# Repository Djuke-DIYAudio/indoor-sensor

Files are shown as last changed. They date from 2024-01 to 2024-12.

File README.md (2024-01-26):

# Indoor sensor
This project contains the open source design files of an affordable indoor air sensor that can accurately measure CO2 level, Temperature, Humidity and Pressure. It contains a ESP8266 wi-fi module making it easy to integrate with your home automation system. 

Possible use cases:
* Monitoring sensor values over time
* Switching of air ventilation based on CO2 or humidity level
* Regulating room temperature (airco or heater)

# Design

## Considerations
At the moment the design considerations are:

* MH-Z19 sensor for measuring CO2 ppm
* BME280 sensor for measuring temperature, humidity and pressure sensor
* ESP8266 module to easily integrate with WIFI in the smart home
* red/green dual LED for level indication
  - Green, PPM < 800
  - Yellow/Orange, 800 < PPM < 1400
  - Red, PPM > 1400
* Connectors for optional 0.91 inch or 0.96 inch SSD1306 display
* Sales price around 25 euros

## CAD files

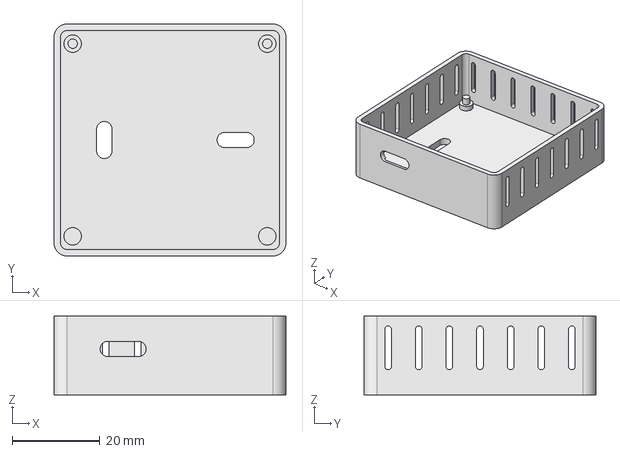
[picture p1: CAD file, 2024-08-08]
Design/Housing/Housing-Bottom.FCStd
53.0 x 53.0 x 18.0 mm

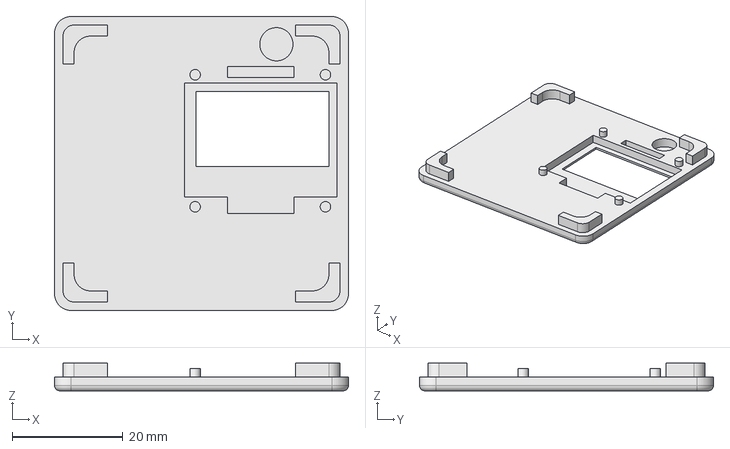
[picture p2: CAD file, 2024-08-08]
Design/Housing/Housing-Top.FCStd
53.0 x 53.0 x 5.00 mm

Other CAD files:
Design/Housing/Housing-Bottom.stl
Design/Housing/Housing-Top.stl

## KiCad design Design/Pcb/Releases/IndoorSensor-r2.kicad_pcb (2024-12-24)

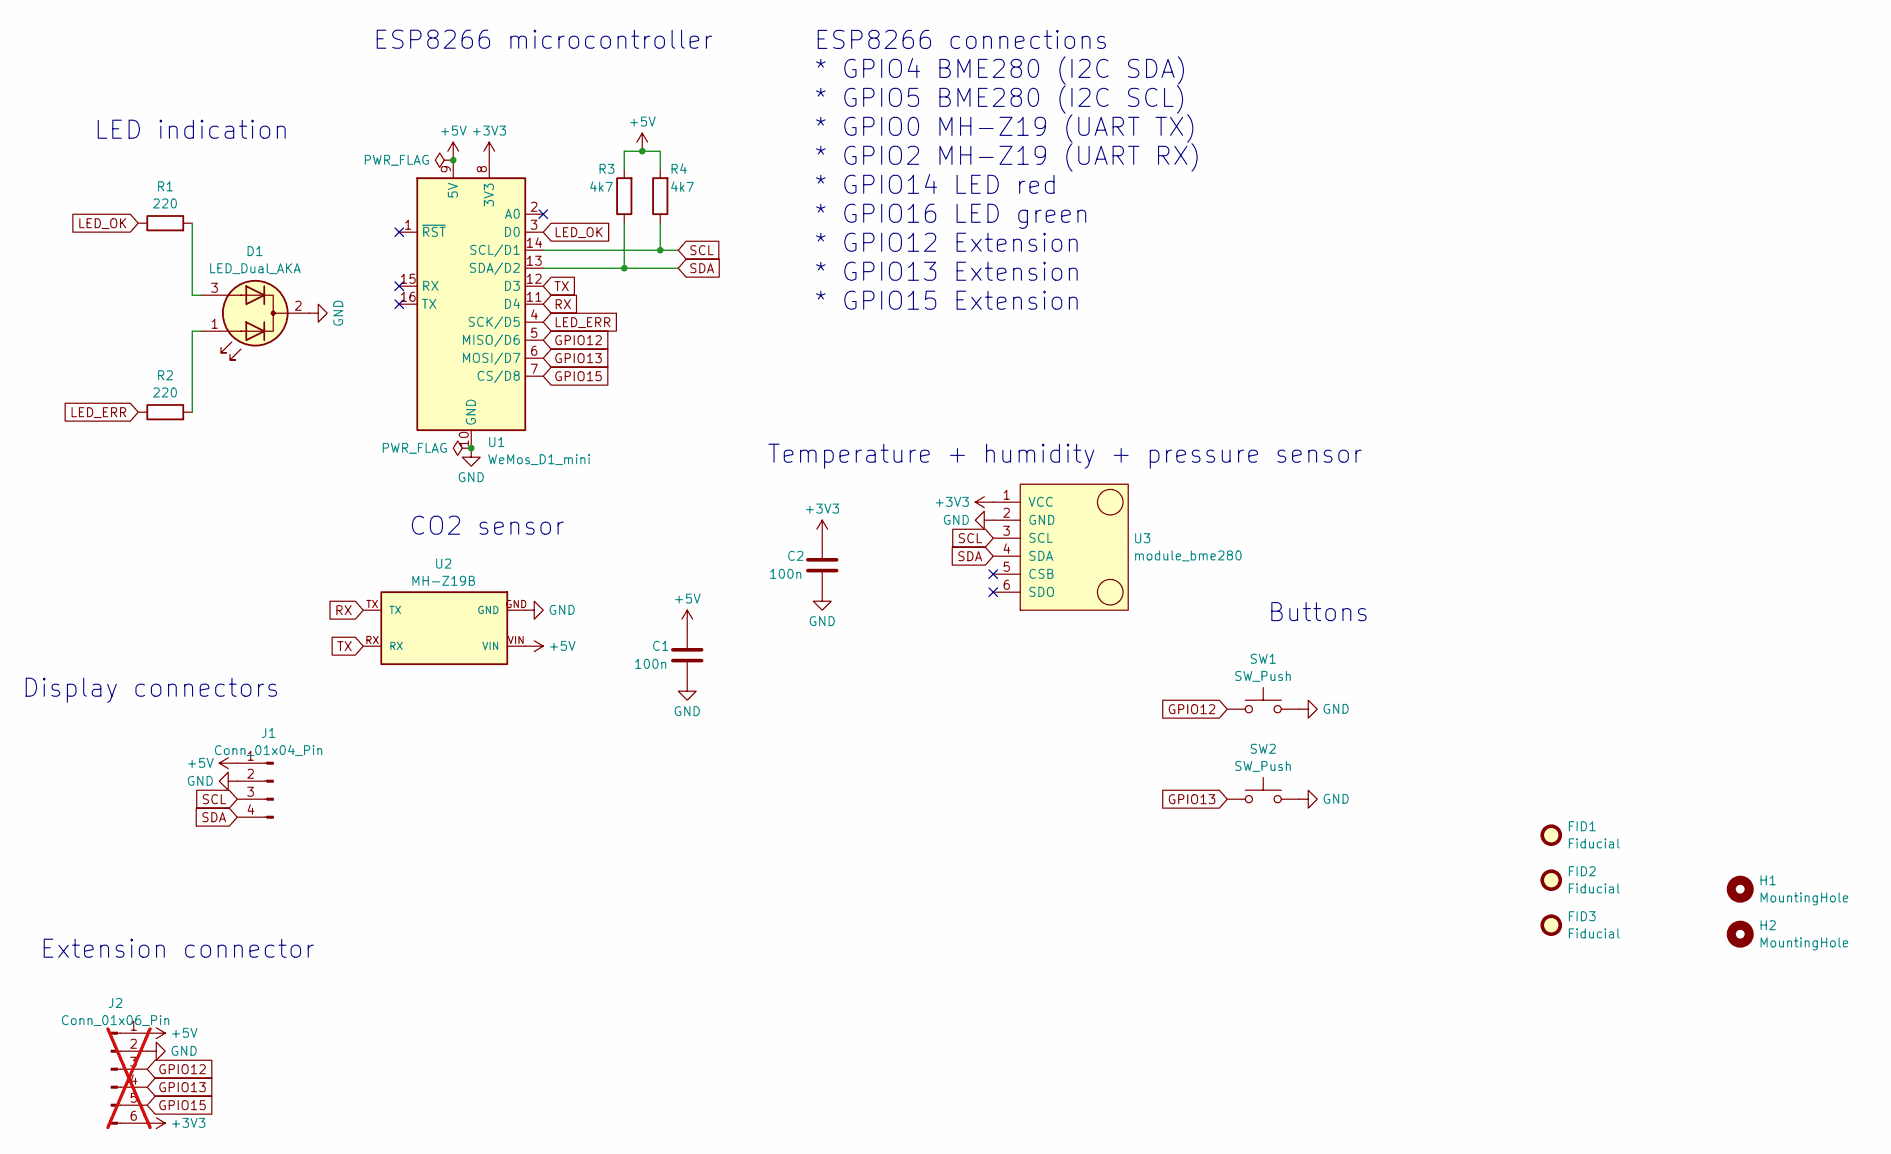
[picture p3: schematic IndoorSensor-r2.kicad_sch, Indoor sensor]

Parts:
C1, C2: 100n; C_0805_2012Metric
D1: LED_Dual_AKA; LED_D3.0mm-3
FID1, FID2, FID3: Fiducial; Fiducial_1mm_Mask2mm
H1, H2: MountingHole; MountingHole_2.2mm_M2
J1: Conn_01x04_Pin; PinSocket_1x04_P2.54mm_Vertical
J2: Conn_01x06_Pin; PinSocket_1x06_P2.54mm_Vertical; not fitted
R1, R2: 220; R_0805_2012Metric
R3, R4: 4k7; R_0805_2012Metric
SW1, SW2: SW_Push; SW_PUSH_6mm_H5mm
U1: WeMos_D1_mini; WEMOS_D1_mini_light
U2: MH-Z19B; MH-Z19B-FOOT
U3: module_bme280

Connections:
+3V3: C2.1, J2.6, U1.8 (3V3), U3.1 (VCC)
+5V: C1.1, J1.1, J2.1, R3.2, R4.2, U1.9 (5V), U2.VIN
GND: C1.2, C2.2, D1.2 (K), J1.2, J2.2, SW1.2, SW2.2, U1.10 (GND), U2.GND, U3.2 (GND)
GPIO12: J2.3, SW1.1, U1.5 (MISO/D6)
GPIO13: J2.4, SW2.1, U1.6 (MOSI/D7)
GPIO15: J2.5, U1.7 (CS/D8)
LED_ERR: R2.1, U1.4 (SCK/D5)
LED_OK: R1.1, U1.3 (D0)
unnamed: D1.1 (A1), R2.2
unnamed: D1.3 (A2), R1.2
RX: U1.11 (D4), U2.TX
SCL: J1.3, R4.1, U1.14 (SCL/D1), U3.3 (SCL)
SDA: J1.4, R3.1, U1.13 (SDA/D2), U3.4 (SDA)
TX: U1.12 (D3), U2.RX

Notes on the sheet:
Temperature + humidity + pressure sensor
ESP8266 connections * GPIO4 BME280 (I2C SDA) * GPIO5 BME280 (I2C SCL) * GPIO0 MH-Z19 (UART TX) * GPIO2 MH-Z19 (UART RX) * GPIO14 LED red * GPIO16 LED green * GPIO12 Extension * GPIO13 Extension * GPIO15 Extension
ESP8266 microcontroller
LED indication
Extension connector
CO2 sensor
Display connectors
Buttons

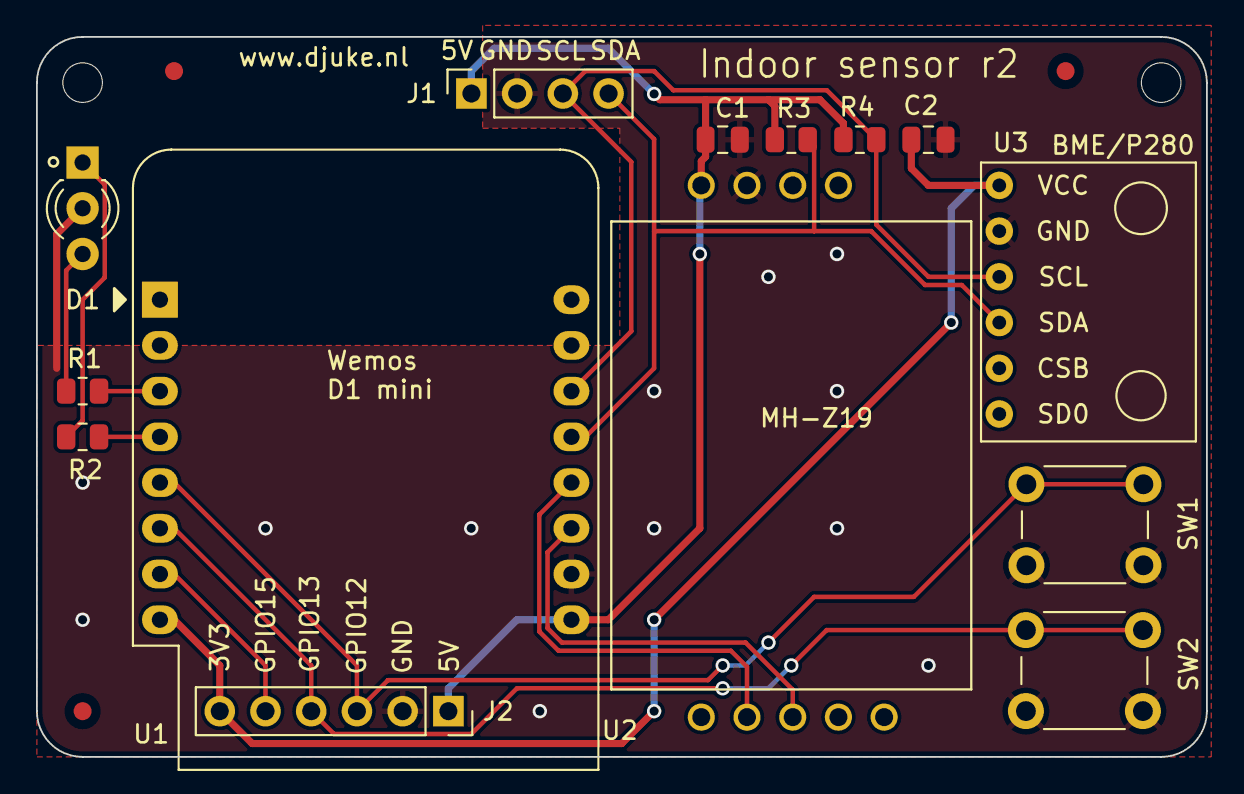
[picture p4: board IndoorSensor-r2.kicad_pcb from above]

Board: 2 copper layers, 65.0 x 40.0 mm, 19 parts (0 on the bottom side), 14 nets.

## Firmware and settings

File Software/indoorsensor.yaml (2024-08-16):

# Configration file for ESPhome for the Djuke indoorsensor
#
# From the command line, it can be run with:
#
# `esphome run indoorsensor`
#
# Using substitutions (see below), some parameters can be configured from the command line
#
# `esphome -s devicename indoor-werkkamer -s wifi_ssid SSID -s wifi_password PASSWD run indoorsensor.yaml`
#

# Substitutions allow keeping parameters organized
# and they can be adjusted from the command line
substitutions:
    devicename: "indoor"
    wifi_ssid: "SSID"
    wifi_password: "Password"
    bme280_temperature_offset: "-8.0"
    bme280_pressure_offset: "+0"
    bme280_humidity_offset: "+26"
    mhz19_temperature_offset: "-5"
    
# Device and board name
esphome:
  name: ${devicename}

esp8266:
  board: d1_mini

# Enable logging
logger:

# Enable Home Assistant API
api:
  password: ""

ota:
  password: ""

# WIFI settings
wifi:
  ssid: ${wifi_ssid}
  password: ${wifi_password}

  # Enable fallback hotspot (captive portal) in case wifi connection fails
  ap:
    ssid: "Indoor sensor Fallback Hotspot"
    password: "Pass1234"

captive_portal:

# Digital outputs for LEDs
output:
  - platform: gpio
    pin: GPIO14
    id: led_red

  - platform: gpio
    pin: GPIO16
    id: led_green
    
# Bus configuration for UART and I2C
uart:
  tx_pin: GPIO0
  rx_pin: GPIO2
  baud_rate: 9600

i2c:
  sda: GPIO4
  scl: GPIO5
  scan: true

# Sensor configuration
sensor:
  - platform: mhz19
    co2:
      name: "CO2 value"
      id: "co2"
      on_value_range:
        - above: 1400
          then:
            - output.turn_on: led_red
            - output.turn_off: led_green
        - below: 1400
          above: 800
          then:
            - output.turn_on: led_red
            - output.turn_on: led_green
        - below: 800
          then:
            - output.turn_on: led_green
            - output.turn_off: led_red
    temperature:
      name: "MHZ19 Temperature"
      filters:
        - offset: ${mhz19_temperature_offset}
    update_interval: 5s
    automatic_baseline_calibration: false

  - platform: bme280
    temperature:
      name: "BME280 Temperature"
      id: "temp"
      oversampling: 1x
      unit_of_measurement: "°C"
      icon: "mdi:water-percent"
      device_class: "temperature"
      state_class: "measurement"
      filters:
        - offset: ${bme280_temperature_offset}
    pressure:
      name: "BME280 Pressure"
      id: "pressure"
      filters:
        - offset: ${bme280_pressure_offset}
    humidity:
      name: "BME280 Humidity"
      id: "humidity"
      filters:
        - offset: ${bme280_humidity_offset}
    address: 0x76
    update_interval: 5s

# Define fonts to be used on the display
font:
  - file: "gfonts://Roboto"
    id: my_font
    size: 32
  - file: "gfonts://Roboto"
    id: my_font_small
    size: 16

# Show bare-minimum auto-ranged graph
graph:
  - id: co2_graph
    border: false
    sensor: co2
    line_type: SOLID
    line_thickness: 2
    y_grid: 1000
    duration: 3hours
    width: 100
    height: 16
    min_value: 400
    max_value: 2000

# Display configutation
display:
  - platform: ssd1306_i2c
    model: "SSD1306 128x64"
    address: 0x3C
    lambda: |-
      it.printf(it.get_width(), 0, id(my_font), TextAlign::TOP_RIGHT, "%.1f°C", id(temp).state);
      it.printf(0, 32, id(my_font_small), "%.0f", id(co2).state);
      it.graph(28, 32, id(co2_graph));
      it.printf(0, 48, id(my_font_small), "%.0f%%", id(humidity).state, id(pressure).state);
      it.printf(it.get_width(), 48, id(my_font_small), TextAlign::TOP_RIGHT, "%.0fhPa", id(pressure).state);

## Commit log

2024-01-26 Add first indoor sensor design
    [IndoorSensor.kicad_pcb, IndoorSensor.kicad_sch]
2024-01-26 Update hole size and 3d references
    [IndoorSensor.kicad_pcb]
2024-01-26 Fix minor issues before production
    [IndoorSensor.kicad_pcb]
2024-08-08 Move PCB design to different folder
    [IndoorSensor.kicad_pcb, IndoorSensor.kicad_sch]
2024-08-08 Add FreeCAD design for the housing
    [Housing-Bottom.FCStd, Housing-Bottom.stl, Housing-Top.FCStd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]
2024-12-24 Add revision 2 design
    [IndoorSensor.kicad_pcb, IndoorSensor.kicad_sch]
2024-12-24 Final rev2 fixes
    [IndoorSensor.kicad_pcb]
2025-02-28 Release Indoor sensor r2
    [IndoorSensor-r2.kicad_pcb, IndoorSensor-r2.kicad_sch]
